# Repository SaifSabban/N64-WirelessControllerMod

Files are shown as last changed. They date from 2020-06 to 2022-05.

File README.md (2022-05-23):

# N64 -Wireless Controller Mod
A modification to your current N64 controller to make it wireless. Based on the Work by micro on the [Universal Wireless Retro Controller](https://nfggames.com/forum2/index.php?topic=5180.0) Click the photo to see a video of the controller in action.

<p align="center">
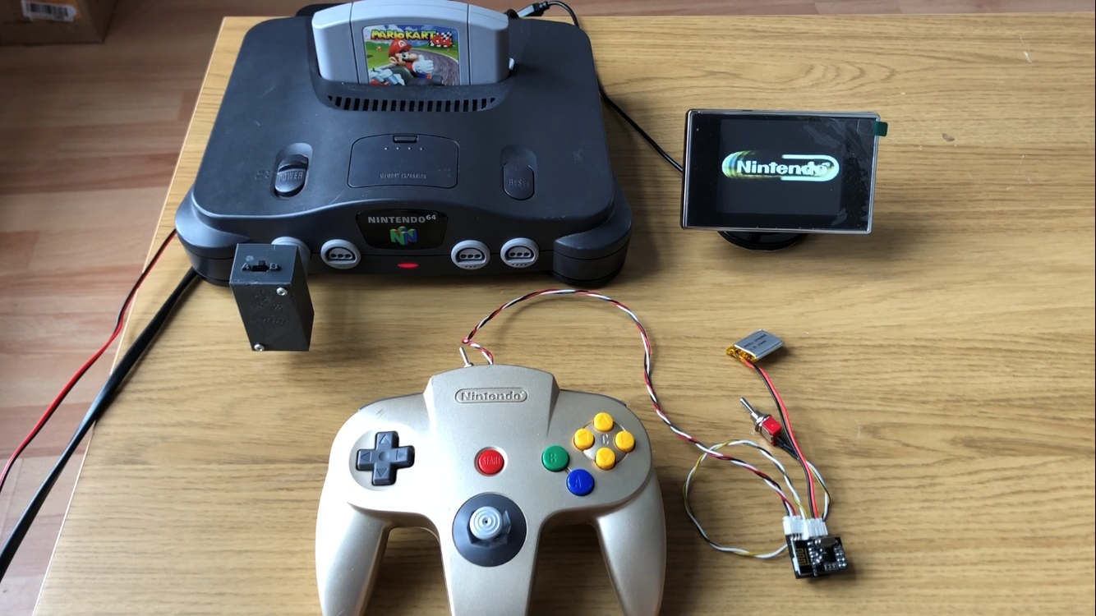
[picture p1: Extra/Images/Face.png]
IMAGE ALT TEXT HERE

<p>

### Notes
This project could use a lot of work, mainly:
1. We could integrate the NRF24L01+ into the PCB boards.
2. Add the components of the Micro-LiPo into the main transmitter PCB Board.
3. Translate the assembly code into Arduino code to allow the use of smaller micro controllers and possibly 2-way communication.

If you press the A button while powering the N64 controller with the mod, you will set the channel to A, while if you press B, you will set it to Channel B.

Know that if you decide to undertake this project, you are the one liable for any damages or risks that might occur.

## Getting Started
### Prerequisites
All the Components that are needed can be found in the bellow list:
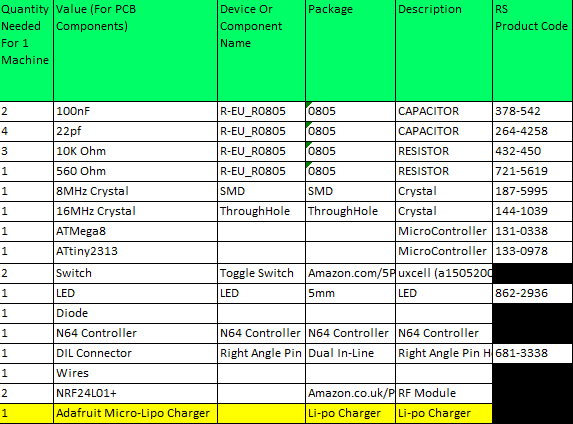
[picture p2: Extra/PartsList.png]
<p align="center"><p>

Optionally you could use JST connectors, instead of soldering wires directly to the PCB. I used the PH series.<br/>
you need to have an [ISP Arduino Programmer](https://docs.arduino.cc/built-in-examples/arduino-isp/ArduinoISP), or use any ISP programmer such as the [USBasp-Programmer](https://hobbycomponents.com/usb-interface/841-usbasp-avr-programmer-adaptor).<br/>
Install and set up [avrdudess](https://avrdudess.software.informer.com/2.4/) There are tons of write-ups on how to do this.<br/>
Print the Receiver's [3D box and Lid](https://github.com/saifsabban/N64-WirelessControllerMod/tree/master/3D-PrintableCase), and use two 2.5M screws to hold it down.<br/>
Print the PCBs for the [Reciever with a SMD microcontroller](https://github.com/saifsabban/N64-WirelessControllerMod/blob/master/N64_Receiver/N64_Receiver_PCB/N64_RX_GerberV2.1.zip) or [Receiver with a DIP microcontroller](https://github.com/saifsabban/N64-WirelessControllerMod/blob/master/N64_Receiver/N64_Receiver_PCB/N64_RX_GerberV2.0.zip) & the [Transmitter](https://github.com/saifsabban/N64-WirelessControllerMod/blob/master/N64_Transmitter/N64_Transmitter_PCB/N64_Tx_V4.0_Gerber.zip)

## Making the Receiver
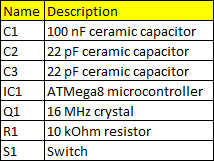
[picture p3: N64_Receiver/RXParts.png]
1. Populate the Receiver PCB with the appropriate parts (The essential resistors & capacitor can be either SMD or Through-Hole):<br/><p align="center"><p>
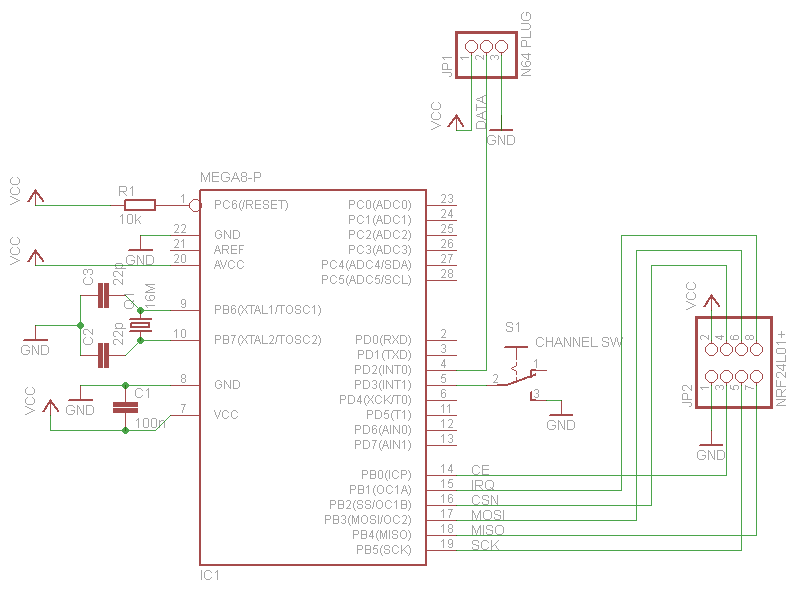
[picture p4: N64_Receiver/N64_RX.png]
2. Connect the ISP pins for your desired programmer to the Receiver Board. Hopefully this reference image and the PCB silkscreen will be of some help.<br/><p align="center"><p>
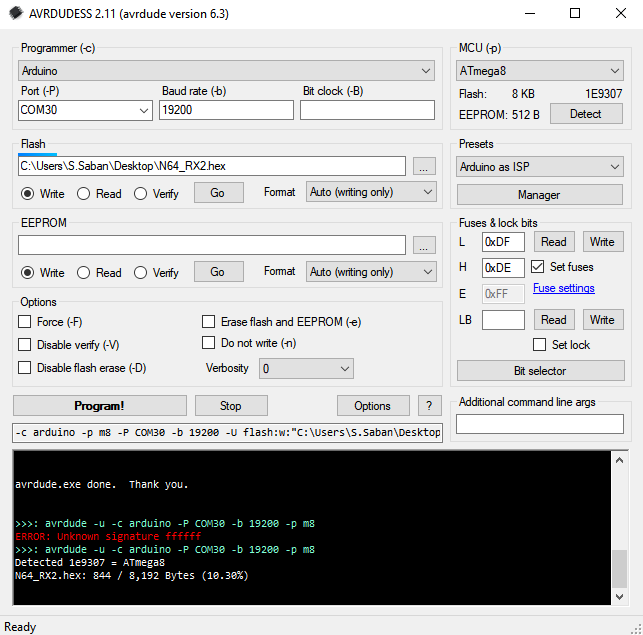
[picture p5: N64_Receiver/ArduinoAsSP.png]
3. Program the Board using AVRdudess with the same parameters shown, MAKE SURE THAT THE HIGH BYTE IS 0xDF & LOW BYTE IS 0xEE. If you don't then you might never be able to use that microcontroller again unless you change the crystal<br/><p align="center"><p>
4. Solder some wire to the switch and solder the other side to the PCB board's SW connector (It doesn't matter which pole of the switch connects to which pad).
5. Cut the N64 plug from the controller, making sure you have some length to route & solder to, I usually keep amount 20cm of cable and cut as necessary.
6. Check the fit of the plug to the printed box, some 3D printers make the opening too large or too small.
7. Glue the Connector to the BOX.
8. Solder the Red wire to the + pad on the connector labelled N64, the black wire to the pad labelled - and the white wire to the pad in the middle of both + & -.
9. Attach (or solder) the NRF24L01+ board onto the Receiver PCB.
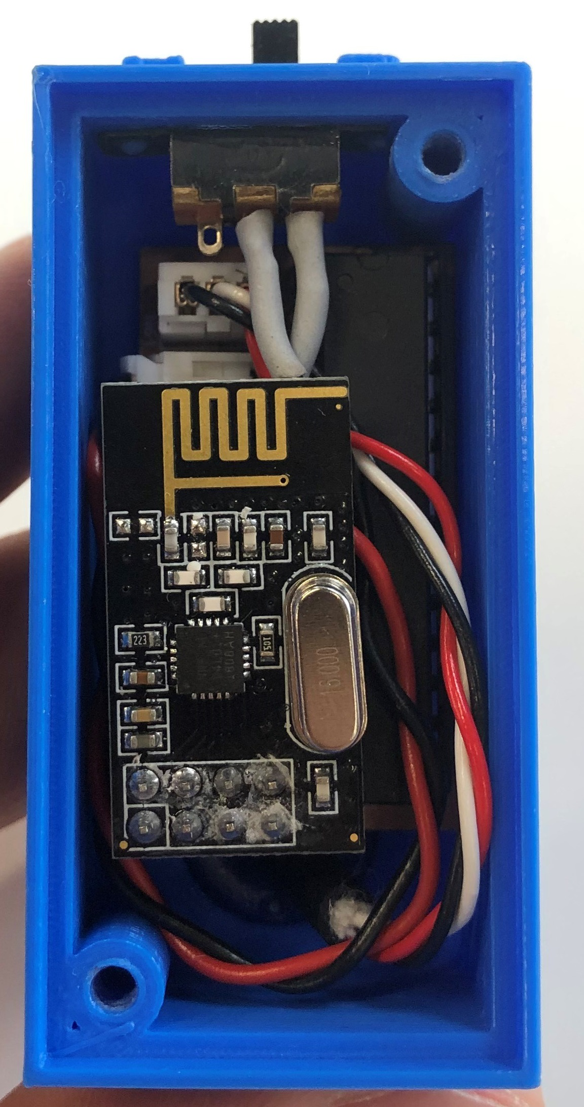
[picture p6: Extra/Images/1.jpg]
10. Place and glue all the parts inside the 3D printed box (As shown) and screw on the Lid<br/><p align="center"><p>

## Making the Transmitters
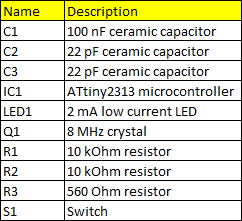
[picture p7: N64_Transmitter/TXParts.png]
1. Populate the Transmitter PCB with the appropriate parts:<br/><p align="center"><p>
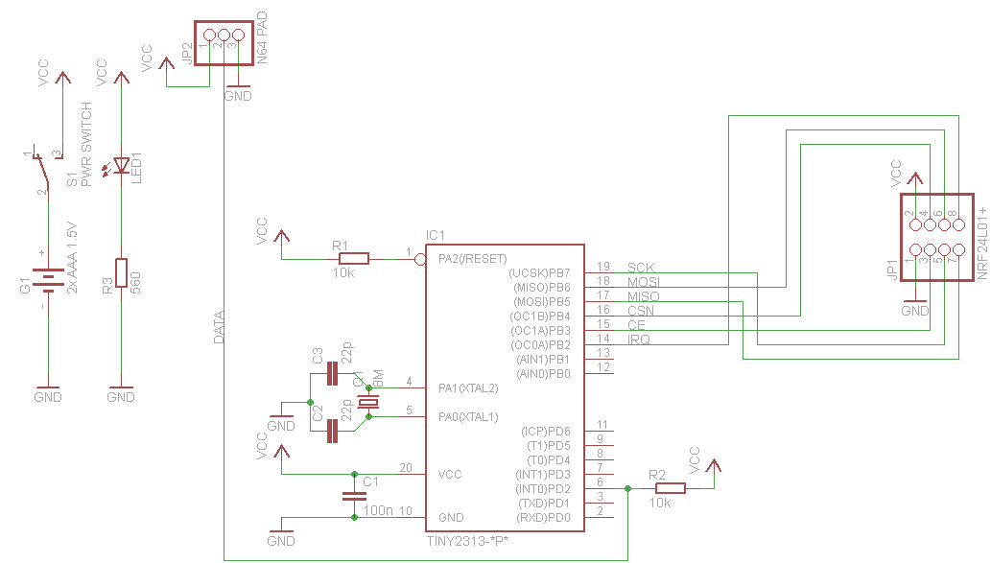
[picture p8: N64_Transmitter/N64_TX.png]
2. Connect the ISP pins for your desired programmer to the Transmitter Board. Hopefully this reference image will be of some help (the pins are in the same location as the connector on the Transmitter PCB, the Ground pin is the one that is highlighted)<br/><p align="center"><p>
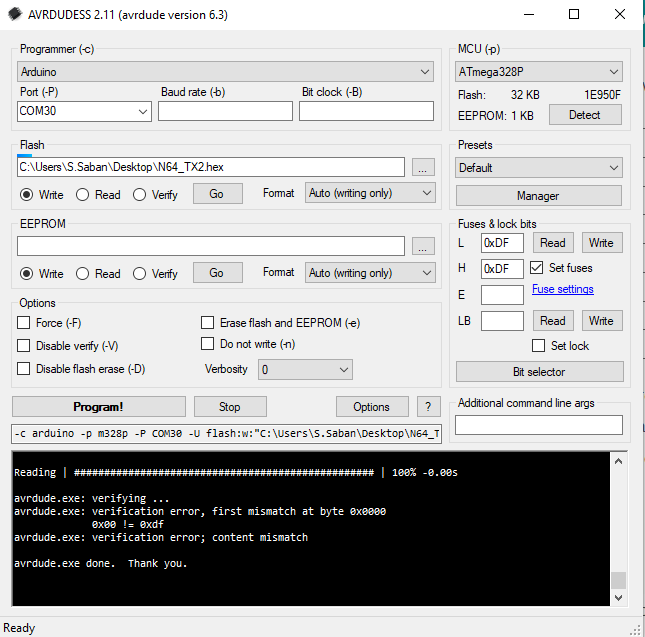
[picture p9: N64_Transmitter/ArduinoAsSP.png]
3. Program the Board using AVRdudess with the same parameters shown, MAKE SURE THAT THE HIGH BYTE IS 0xDF & LOW BYTE IS 0xDF. If you don't then you might never be able to use that microcontroller again unless you change the crystal<br/><p align="center"><p>
4. Disassemble the N64 Controller.
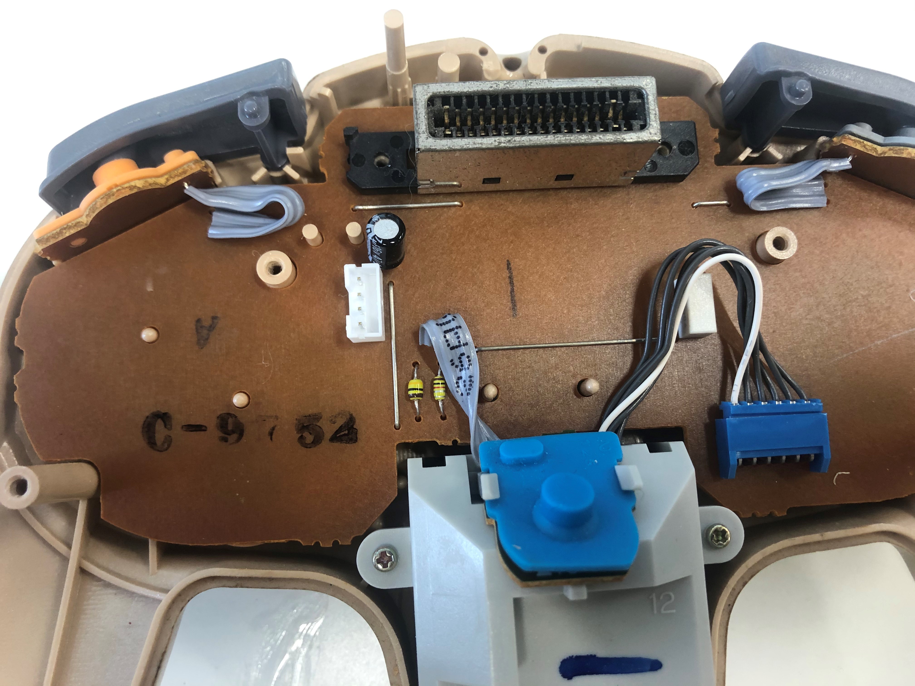
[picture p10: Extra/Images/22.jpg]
5. Desolder the original blue connector that connects to the cable. (I would strongly advise soldering a JST 4 pin PH female connector as shown in the photo below)<br/><p align="center"><p>
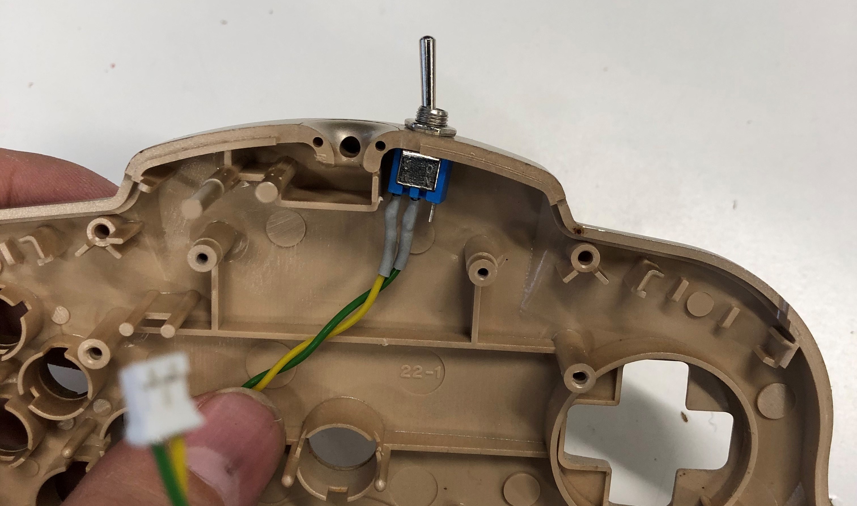
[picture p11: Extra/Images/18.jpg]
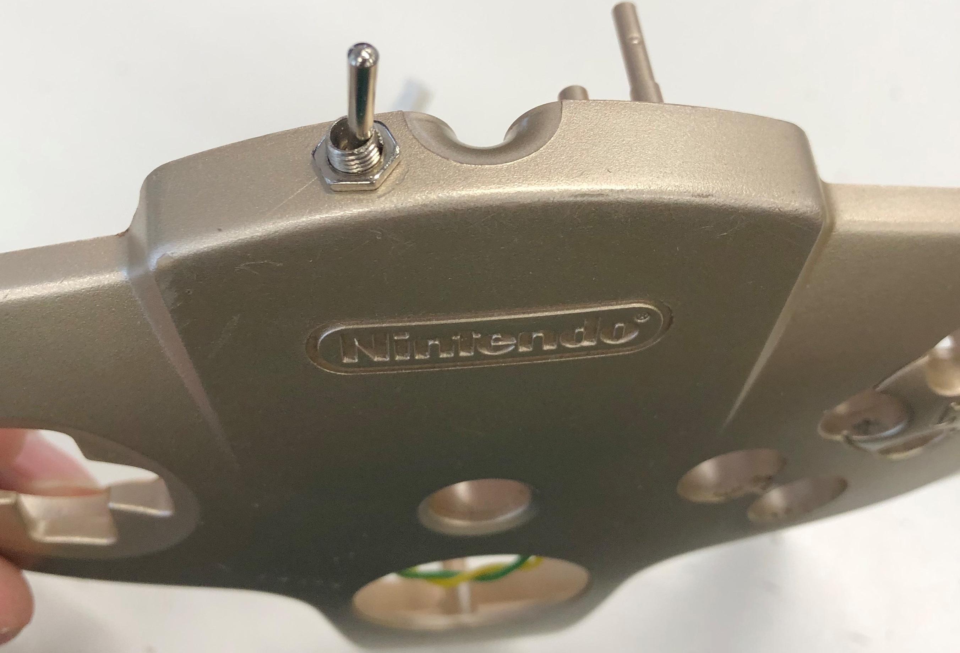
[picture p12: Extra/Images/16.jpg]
6. Check the Size of your switch as around 4.8mm, and proceed to drill a 5mm hole at the button half of the controller (See images), solder some wires to them and screw them onto the controller<br/><p align="center"><p><br/><p align="center"><p>
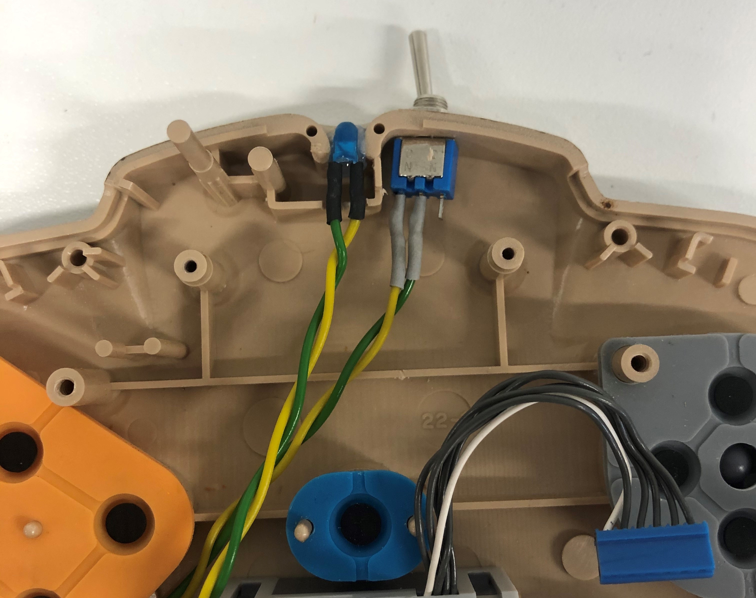
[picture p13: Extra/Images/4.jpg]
7. Solder some wires to the 5mm LED and hotglue it into the hole that the old controller wire used to come out of. (Keep a note which wire is positive and which is negative) <br/><p align="center"><p>
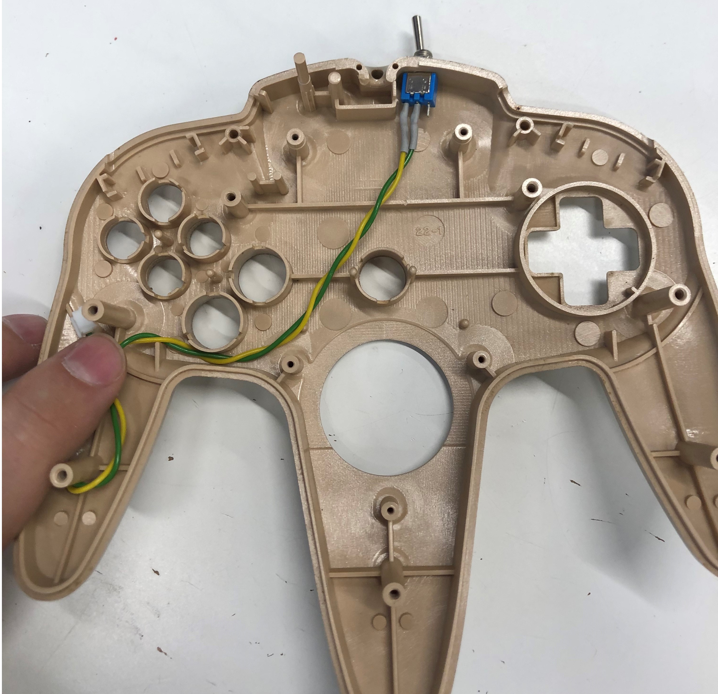
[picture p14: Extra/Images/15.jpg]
8. route the wires switch and LED wires to the "Right Hand" area of the controller.<br/><p align="center"><p>
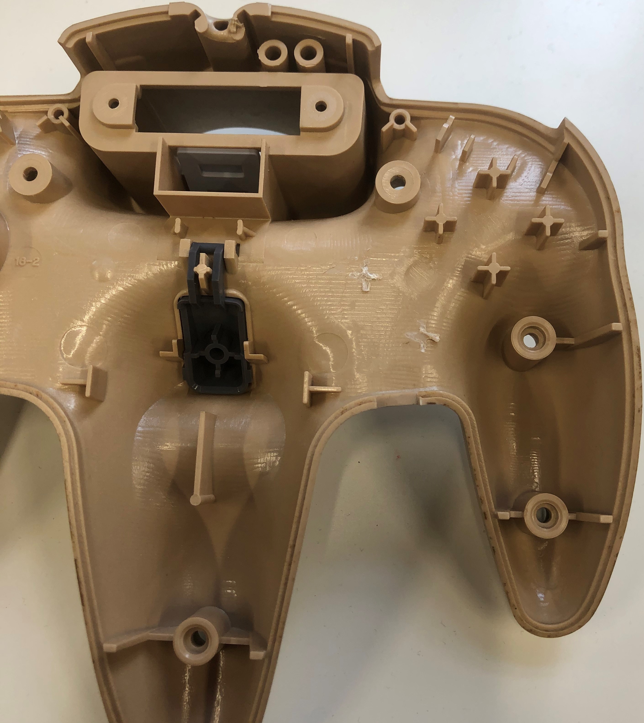
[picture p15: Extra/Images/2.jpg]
9. Remove the 2 lower "Crosses" that brace the buttons, from the bottom half of the controller.<br/><p align="center"><p>
10. solder wires to the "Bat" pin and the "GND" pin on the Adafruit Micro lipo.
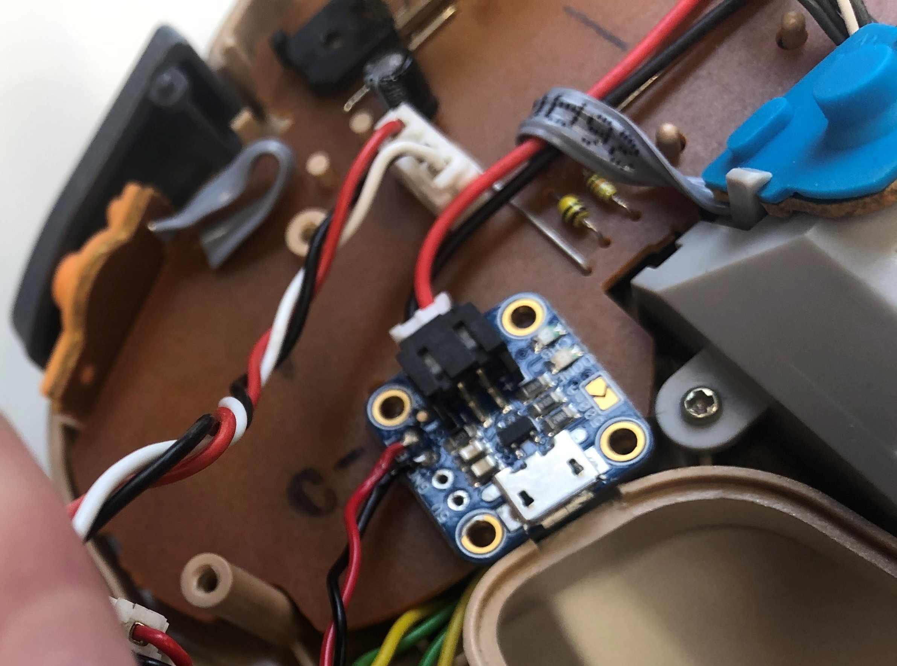
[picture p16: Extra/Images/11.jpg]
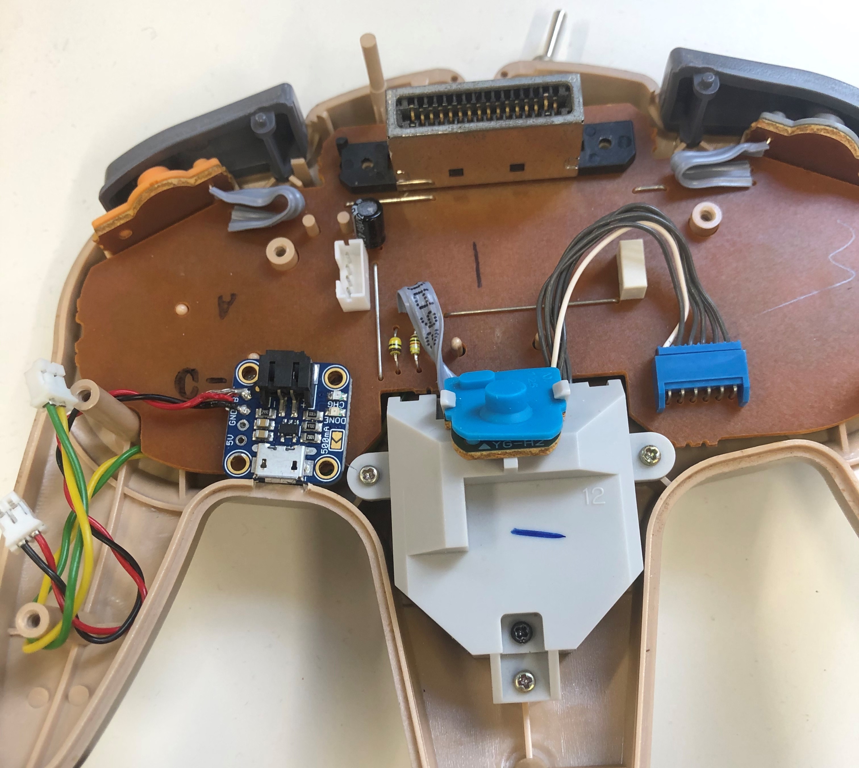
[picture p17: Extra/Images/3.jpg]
11. Place the Micro lipo at the Right-hand side of the controller, and cut a bit off the corresponding top and bottom half edges to allow the USB charger through.<br/><p align="center"><p><br/><p align="center"><p>
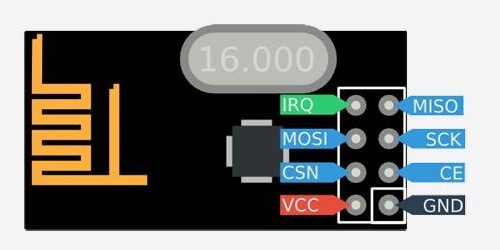
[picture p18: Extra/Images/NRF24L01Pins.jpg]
12. Desolder the Pins on the NRF24L01+ and solder wires to each pin, remembering which wire corresponds to which pin.<br/><p align="center"><p>
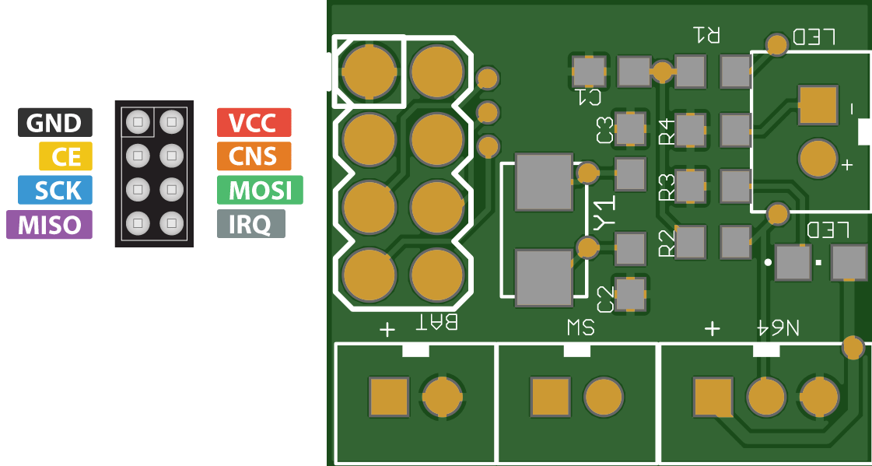
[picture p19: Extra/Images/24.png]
13. leave some length and solder the other side of the wires from step 11 to the Custom board.<br/><p align="center"><p>
14. Solder the LED and Switch wires to the Main PCB, making sure the polarity of the LED wires are correct (- pin is Ground, + pin is 3.3V).
15. Solder the wires from the Micro lipo, to the Custom board's Bat pins, making sure that the Bat pin solders to the pin marked with a +.
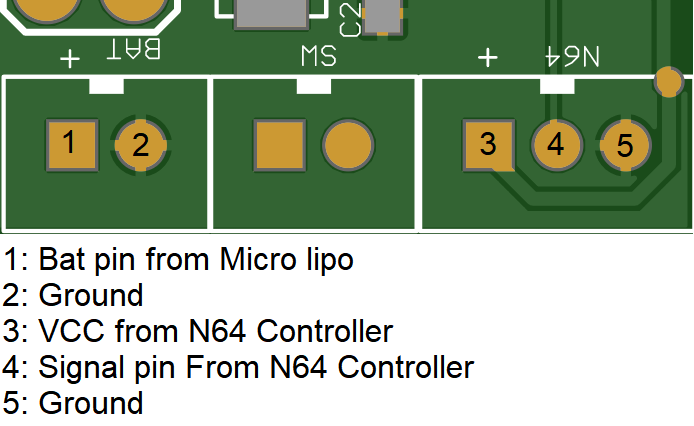
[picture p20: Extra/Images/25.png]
16. Solder the wires From the N64 controller board to the custom board, Pin order is VCC (Denoted by the + sign on top), signal wire, and ground. <br/><p align="center"><p>
17. Attach a battery to the micro lipo and test the mod. Remember if you press the A button while powering the N64 controller with the mod, you will set the channel to A, while if you press B, you will set it to Channel B.
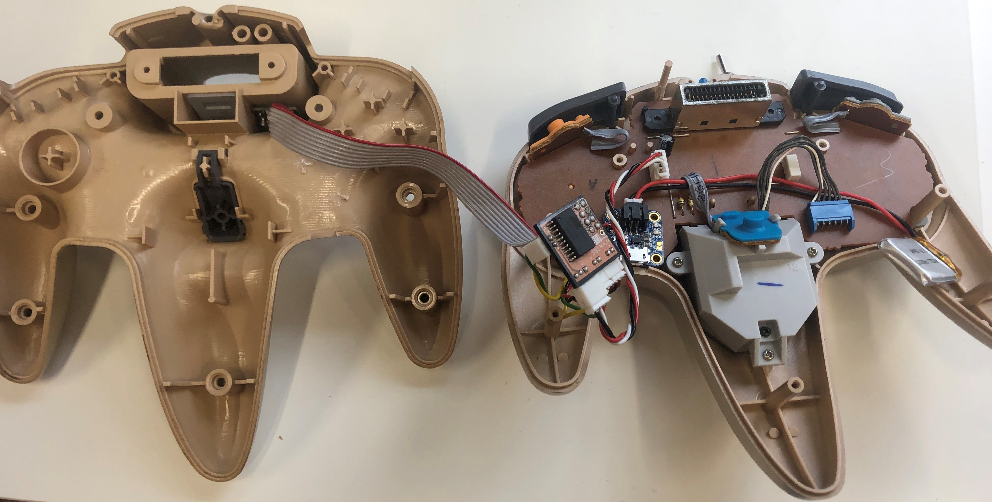
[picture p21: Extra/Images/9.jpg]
18. If all works button up your device. I recommend routing the battery to the Left hand side of the controller, the custom board to the Right, and feeding the NRF24L01+ into the nook of the expantion slot.<br/><p align="center"><p>

## Warnings!!
Make sure the polarity of the receiver pins is correct or you risk blowing the N64's power module, or worse, frying the N64 completely. In you connect the Batter pins or the N64 pins to the wrong wires you risk frying you N64 controller. I've tried this mod on reproduction N64 controllers, but it seems they allow some electrical noise that messes us the communication pathways and making it seem like you've pressed buttons you didn't actually press. If you mess with the power pins on the NRF24L01+ you risk breaking either your n64 or the controller, depending on which one was wrongfully connected. However, messing up the data pins of the NRF24L01+ breaks nothing. If the battery is too low, it will keep the LED light on, but might not send any control signals to the receiver.

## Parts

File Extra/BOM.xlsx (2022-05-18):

Quantity Needed For 1 Machine | Value (For PCB Components) | Device Or Component Name | Package | Description | RS Product Code | Cost For Each Component | Minimum Quantity Order | How Many Components Needed For All Machines | How Many Parts To Purchase For All Machines | Costs For Total Parts Needed To Make All Machines | Number of Machines
2 | 100nF | R-EU_R0805 | 0805 | CAPACITOR | 378-542 | £0.003 | 50 | 2 | 50 | £0.15 | 1
4 | 22pf | R-EU_R0805 | 0805 | CAPACITOR | 264-4258 | £0.010 | 25 | 4 | 25 | £0.25 | Make Cheaper By Making
3 | 10K Ohm | R-EU_R0805 | 0805 | RESISTOR | 432-450 | £0.004 | 100 | 3 | 100 | £0.40
1 | 560 Ohm | R-EU_R0805 | 0805 | RESISTOR | 721-5619 | £0.028 | 5 | 1 | 5 | £0.14
1 | 8MHz Crystal | SMD | SMD | Crystal | 187-5995 | £0.130 | 25 | 1 | 25 | £3.25
1 | 16MHz Crystal | ThroughHole | ThroughHole | Crystal | 144-1039 | £0.213 | 25 | 1 | 25 | £5.33
1 | ATMega8 |  |  | MicroController | 131-0338 | £1.860 | 2 | 1 | 2 | £3.72
1 | ATtiny2313 |  |  | MicroController | 133-0978 | £0.844 | 5 | 1 | 5 | £4.22
2 | Switch | Toggle Switch | Amazon.com/5Pcs-Thread-Latching-Toggle-Switch/dp/B0147XIKDE | uxcell (a15052000ux0140) |  | £1.000 | 5 | 2 | 5 | £5.00
1 | LED | LED | 5mm | LED | 862-2936 | £0.000 | 1 | 1 | 1 | £0.00
1 | Diode |  |  |  |  | £0.000 | 1 | 1 | 1 | £0.00
1 | N64 Controller | N64 Controller | N64 Controller | N64 Controller |  | £25.000 | 1 | 1 | 1 | £25.00
1 | DIL Connector | Right Angle Pin Header | Dual In-Line | Right Angle Pin Header | 681-3338 | £0.000 | 1 | 1 | 1 | £0.00
1 | Wires |  |  |  |  | £0.000 | 1 | 1 | 1 | £0.00
2 | NRF24L01+ |  | Amazon.co.uk/PIXNOR-Professional-NRF24L01-Wireless-Transceiver/dp/B010N32SGM/ref=sr_1_4?keywords=NRF24L01%2B&qid=1582118209&s=electronics&sr=1-4 | RF Module |  | £1.418 | 5 | 2 | 5 | £7.09
1 | Adafruit Micro-Lipo Charger |  | Li-po Charger | Li-po Charger | adafruit.com/product/1904 | £6.950 | 1 | 1 | 1 | £6.95
 |  |  |  |  |  |  |  |  | Total Cost For All Machines | £61.50
 |  |  |  |  |  |  |  |  | Relative Cost Of Each Machine | £61.50

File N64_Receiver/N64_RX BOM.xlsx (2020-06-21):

Part | Value | Footprint | RS Code
C1 | 100 nF | 0805 | 378-542
C2 | 22pF | 0805 | 264-4258
C3 | 22pF | 0805 | 264-4258
IC1 | ATMega8 |  | 131-0338
Y1 | 16MHz Crystal | Special | 144-1039
R1 | 10k Ohm | 0805 | 432-450
R2 | 560 Ohm | 0402 | 667-8668 |  | or a 0805 | 432-450
LED2 | Normal LED | 0805
S1 | Switch |  | 734-7154
NRF24L01+ | RF | 2x4 SIL |  | ebay.co.uk/i/293157600466?chn=ps&var=592026070810&norover=1&mkevt=1&mkrid=710-134428-41853-0&mkcid=2&itemid=592026070810_293157600466&targetid=878020360040&device=c&mktype=pla&googleloc=1006867&campaignid=9461445814&mkgroupid=97644908122&rlsatarget=pla-878020360040&abcId=1139576&merchantid=113716259&gclid=EAIaIQobChMI8suA6qCN6AIVia3tCh1bXAe_EAQYBSABEgKI2vD_BwE
Box | 30*60*20 | Hammond (1551HRBK) | 1974453 | uk.rs-online.com/web/p/general-purpose-enclosures/1974453

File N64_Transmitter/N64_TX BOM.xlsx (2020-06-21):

Part | Value | Footprint | RS Code
C1 | 100 nF | 0402 | 425-1510 | or a 0805 | 378-542 (https://uk.rs-online.com/web/p/mlccs-multilayer-ceramic-capacitors/0378542/)
C2 | 22pF | 0805 | 264-4258
C3 | 22pF | 0805 | 264-4258
IC1 | ATtiny2313 |  | 133-0978
LED1 | 2mA
LED2 | Normal LED | 0805
Y1 | 8MHz Crystal | Special | 187-5995
R1 | 10k Ohm | 0805 | 432-450 | or a 0402 | 430-767
R2 | 10k Ohm | 0805 | 432-450 | or a 0402 | 430-767
R3 | 560 Ohm | 0402 | 667-8668 | or a 0805 | 432-450
S1 | Switch |  | 734-7154
NRF24L01+ | RF | 2x4 SIL | ebay.co.uk/i/293157600466?chn=ps&var=592026070810&norover=1&mkevt=1&mkrid=710-134428-41853-0&mkcid=2&itemid=592026070810_293157600466&targetid=878020360040&device=c&mktype=pla&googleloc=1006867&campaignid=9461445814&mkgroupid=97644908122&rlsatarget=pla-878020360040&abcId=1139576&merchantid=113716259&gclid=EAIaIQobChMI8suA6qCN6AIVia3tCh1bXAe_EAQYBSABEgKI2vD_BwE
Diode?

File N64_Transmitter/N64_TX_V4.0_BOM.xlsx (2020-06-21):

Part | Value | Footprint | RS Code
C1 | 100nF | 0603 | 698-3251
C2 | 22pF | 0603 | 393-6716
C3 | 22pF | 0603 | 393-6716
IC1 | ATtiny2313 | Special | 133-0978
LED2 | Normal LED | 0805 | 692-0935
Y1 | 8MHz Crystal | Special | 813-6093
R1 | 10k Ohm | 0603 | 740-8805
R2 | 10k Ohm | 0603 | 740-8805
R3 | 560 Ohm | 0603 | 631-6339
R4 | 560 Ohm | 0603 | 631-6339
LED1 | 2mA | Wire
S1 | Switch |  | amazon.co.uk/5Pcs-Thread-Latching-Toggle-Switch/dp/B0147XIKDE
NRF24L01+ | RF | 2x4 SIL | ebay.co.uk/i/293157600466?chn=ps&var=592026070810&norover=1&mkevt=1&mkrid=710-134428-41853-0&mkcid=2&itemid=592026070810_293157600466&targetid=878020360040&device=c&mktype=pla&googleloc=1006867&campaignid=9461445814&mkgroupid=97644908122&rlsatarget=pla-878020360040&abcId=1139576&merchantid=113716259&gclid=EAIaIQobChMI8suA6qCN6AIVia3tCh1bXAe_EAQYBSABEgKI2vD_BwE

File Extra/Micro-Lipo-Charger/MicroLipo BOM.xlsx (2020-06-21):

Part | Value | Footprint | RS Code | Cost | minimum order
C1 | 10uF | 0805 | 749-2125 | 0.01 | 25
C2 | 10uF | 0805 | 749-2125 | 0.01 | 25
IC1 | MCP73831 | SOT-23 | 738-6360 | 0.434 | 5
CHG | Normal LED | 0805 | 654-5818 | 0.062 | 50
Done | Normal LED | 0805 | 121-7785 | 0.062 | 50
R1 | 470 Ohm | 0805 | 721-5619 | 0.009 | 25
R2 | 470 Ohm | 0805 | 721-5619 | 0.009 | 25
R3 | 10k Ohm | 0805 | 432-450 | 0.004
R3 | 2K Ohm | 0805 | 812-3508 | 0.01 | 25
USB | Micro USB | 105017-0001 | 848-6764 | 0.628 | 5
 |  |  |  | 1.238

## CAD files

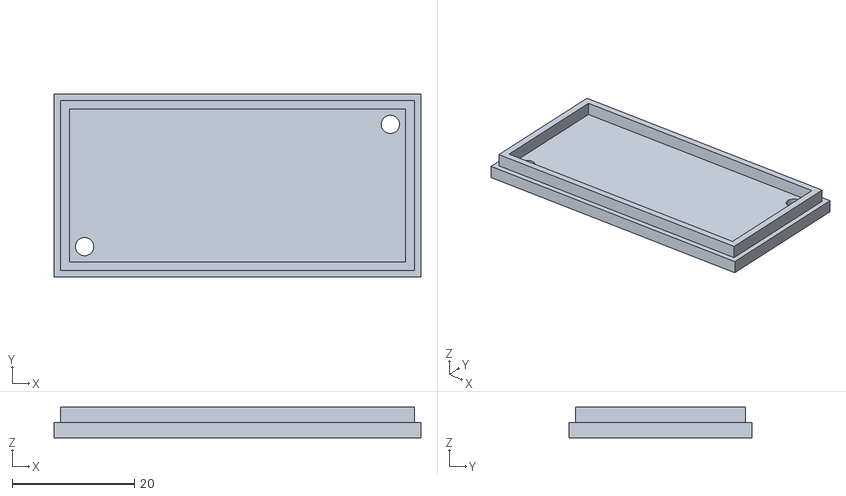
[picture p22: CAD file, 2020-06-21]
3D-PrintableCase/N64 Lid.stl
60.0 x 30.0 x 5.00

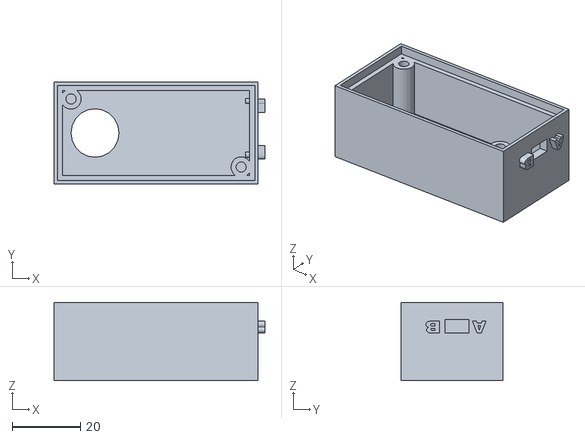
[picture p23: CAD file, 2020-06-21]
3D-PrintableCase/N64 Case.stl
62.0 x 30.0 x 23.0

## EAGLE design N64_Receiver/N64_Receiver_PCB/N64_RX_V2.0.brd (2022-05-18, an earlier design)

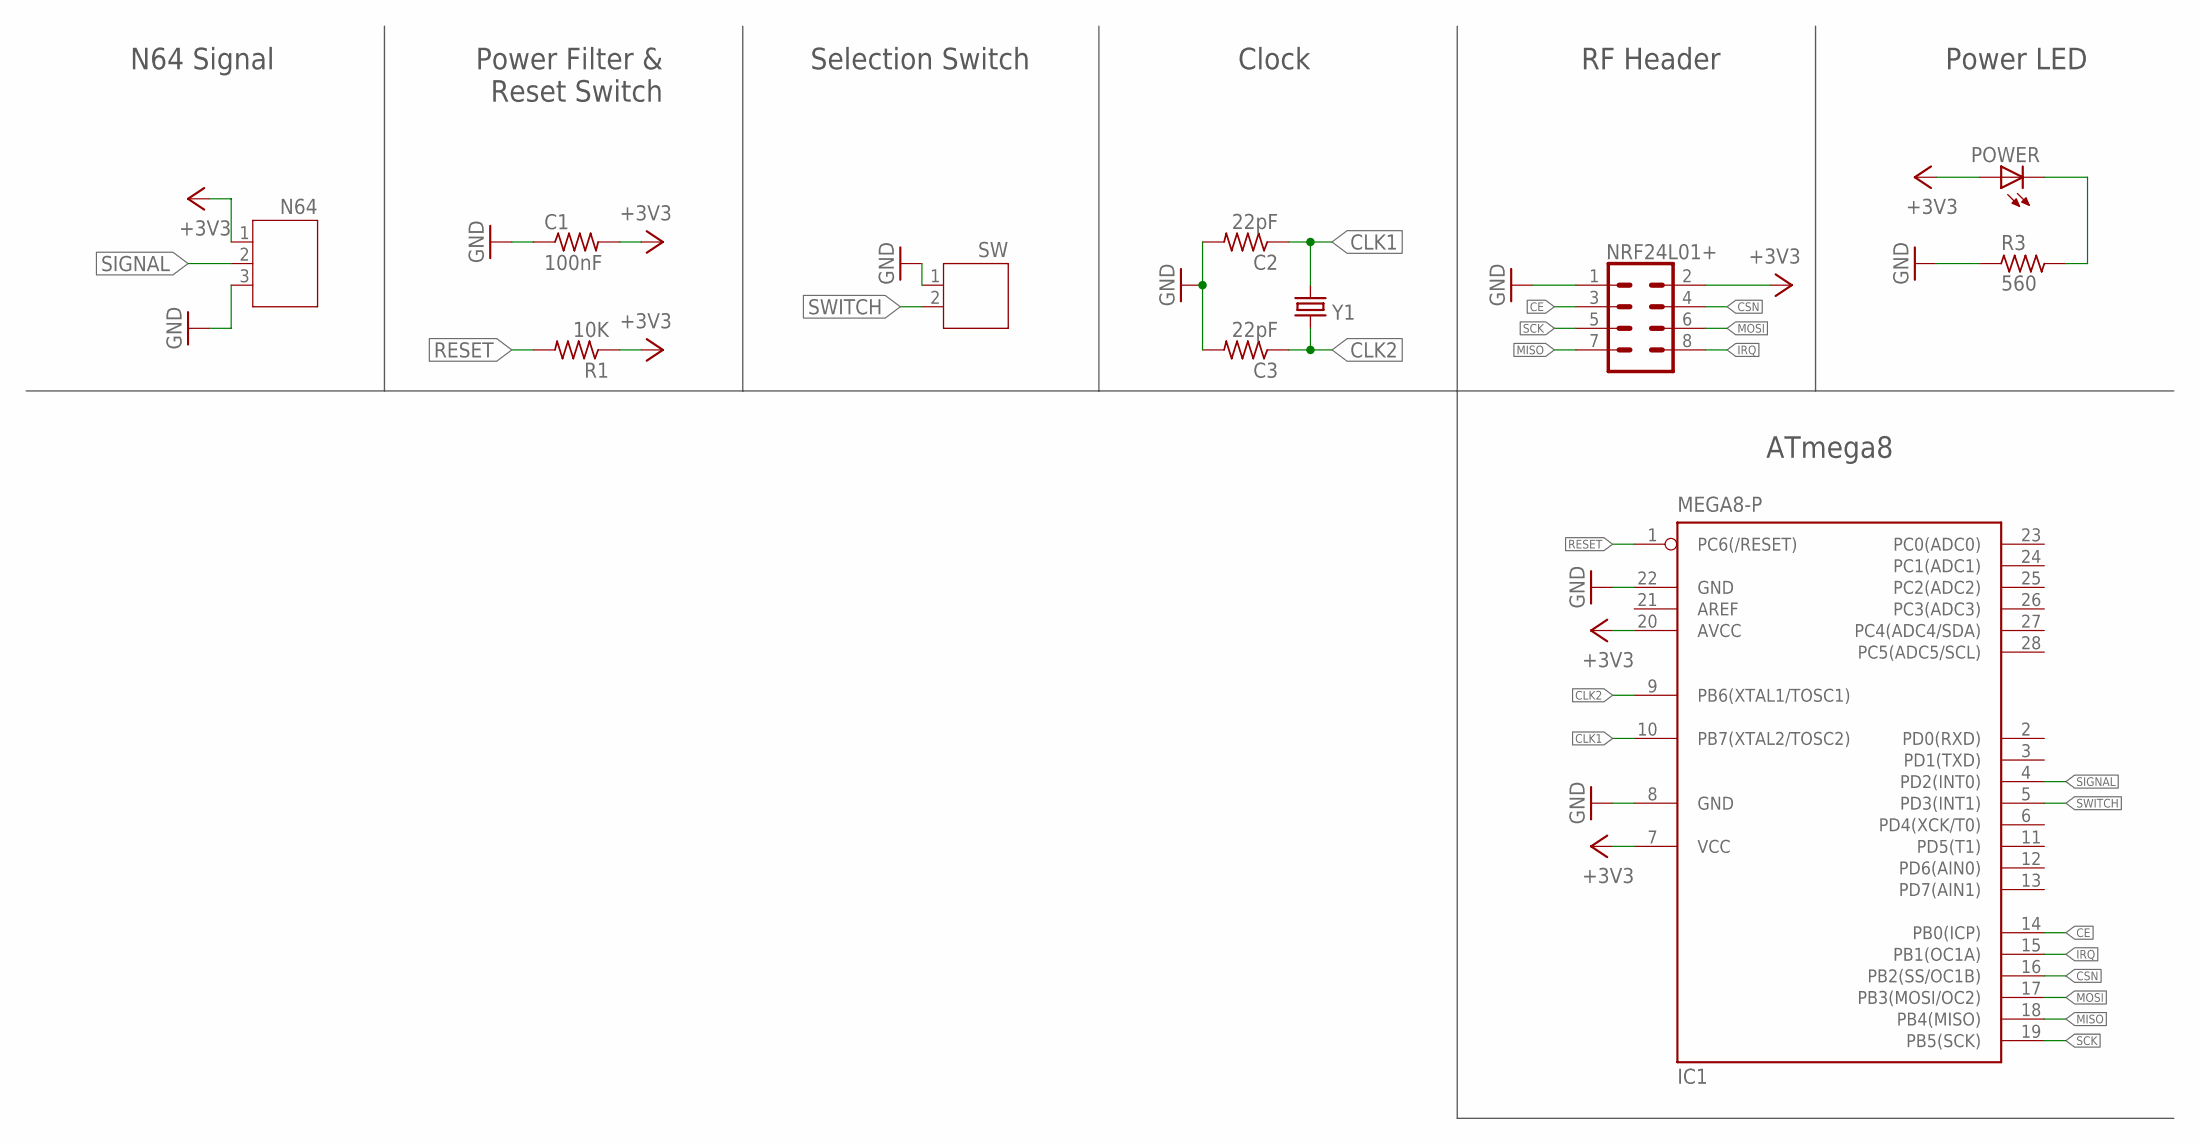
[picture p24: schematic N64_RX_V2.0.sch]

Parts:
C1: 100nF; 0805-THM
C2, C3: 22pF; 0805-THM
IC1: MEGA8-P; DIL28-3
N64: JST-PH3TH; JST-PH3
NRF24L01+: CONN_04X2; 2X4
POWER: LEDCHIPLED_0805; CHIPLED_0805
R1: 10K; 0805-THM
R3: 560; R0805
SW: JST-PH2TH; JST-PH2
Y1: CRYSTALHC49S; HC49/S

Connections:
+3V3: C1.2, IC1.7 (VCC), IC1.20 (AVCC), N64.1, NRF24L01+.2, POWER.A, R1.1
CE: IC1.14 (PB0(ICP)), NRF24L01+.3
CLK1: C2.1, IC1.10 (PB7(XTAL2/TOSC2)), Y1.2
CLK2: C3.1, IC1.9 (PB6(XTAL1/TOSC1)), Y1.1
CSN: IC1.16 (PB2(SS/OC1B)), NRF24L01+.4
GND: C1.1, C2.2, C3.2, IC1.8 (GND), IC1.22 (GND), N64.3, NRF24L01+.1, R3.1, SW.1
IRQ: IC1.15 (PB1(OC1A)), NRF24L01+.8
MISO: IC1.18 (PB4(MISO)), NRF24L01+.7
MOSI: IC1.17 (PB3(MOSI/OC2)), NRF24L01+.6
unnamed: POWER.C, R3.2
RESET: IC1.1 (PC6(/RESET)), R1.2
SCK: IC1.19 (PB5(SCK)), NRF24L01+.5
SIGNAL: IC1.4 (PD2(INT0)), N64.2
SWITCH: IC1.5 (PD3(INT1)), SW.2

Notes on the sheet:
N64 Signal
Power Filter & Reset Switch
Selection Switch
Clock
RF Header
ATmega8
Power LED

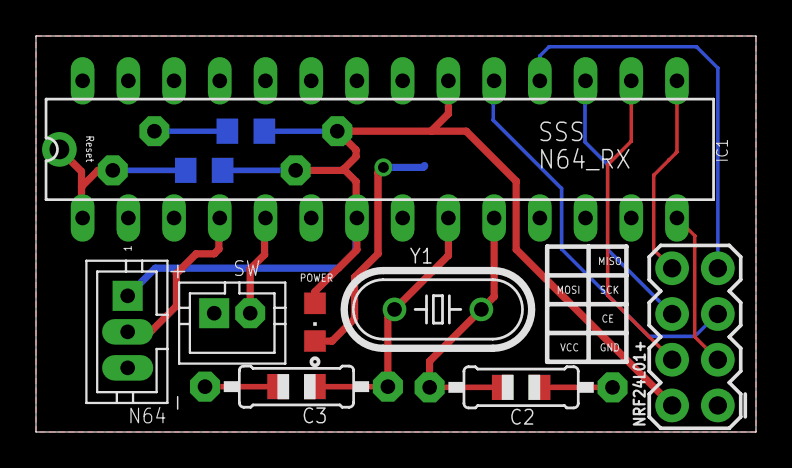
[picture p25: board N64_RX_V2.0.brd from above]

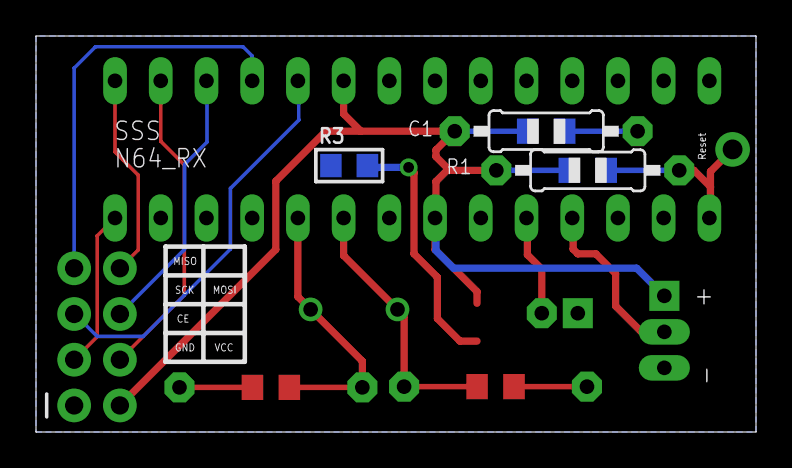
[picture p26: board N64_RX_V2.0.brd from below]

Board: 2 copper layers, 40.0 x 22.0 mm, 11 parts (3 on the bottom side), 14 nets.

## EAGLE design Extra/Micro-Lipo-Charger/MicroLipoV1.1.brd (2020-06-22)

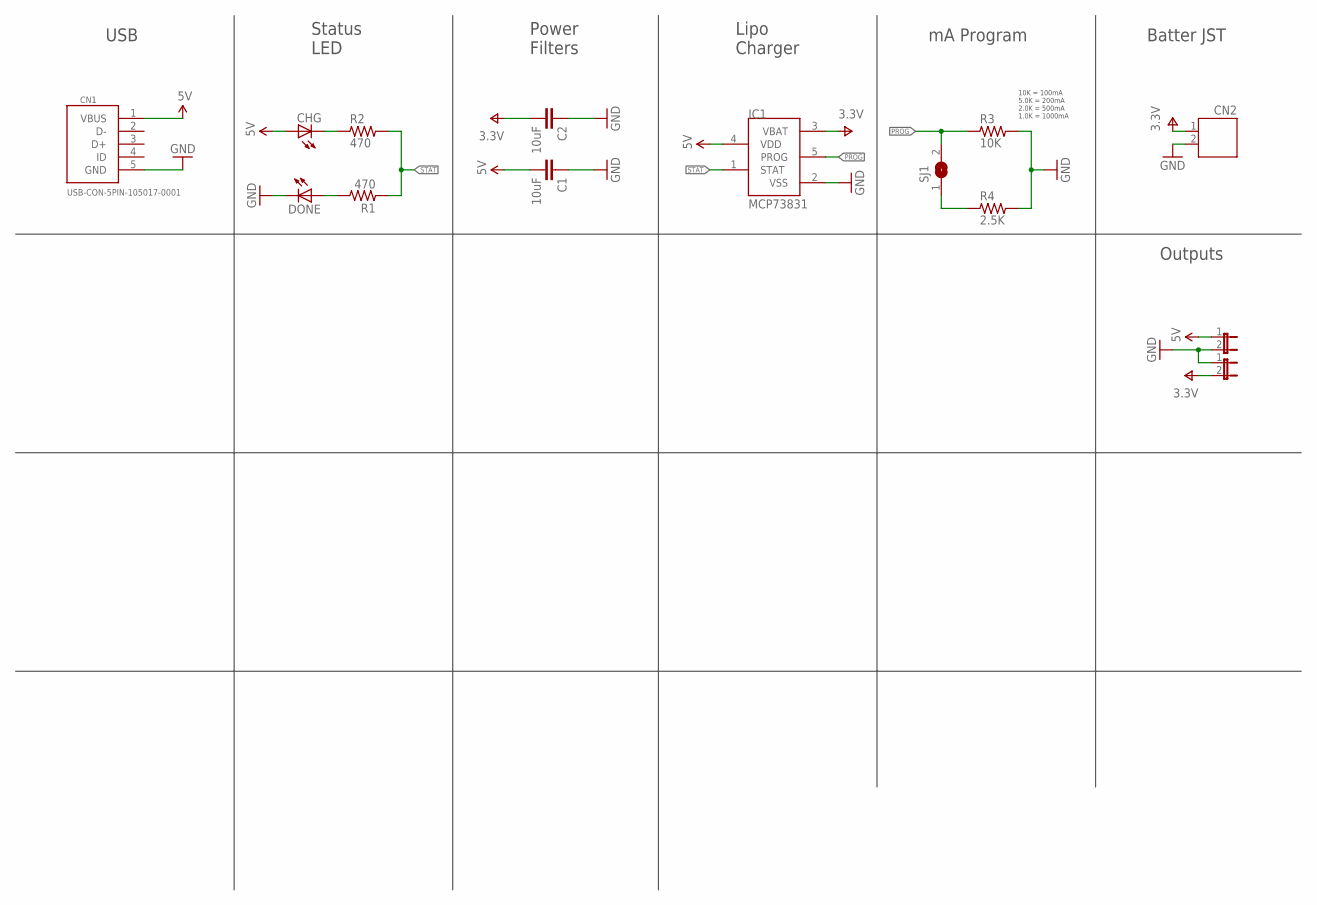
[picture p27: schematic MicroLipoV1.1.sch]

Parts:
C1, C2: 10uF; C0805K
CHG: LEDCHIPLED_0805; CHIPLED_0805
CN1: USB-CON-5PIN-105017-0001; USB-MICRO-MOLEX-105017-0001
CN2: JST-PH2; JST-PH2-S2B
DONE: LEDCHIPLED_0805; CHIPLED_0805
IC1: MCP73831; SOT23-5L
JP2, JP3: JUMPER-2PTH; 1X02
R1, R2: 470; R0805
R3: 10K; R0805
R4: 2.5K; R0805
SJ1: SJ

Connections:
5V: C1.2, CHG.A, CN1.1 (VBUS), IC1.4 (VDD), JP2.1
GND: C1.1, C2.1, CN1.5 (GND), CN2.2, DONE.C, IC1.2 (VSS), JP2.2, JP3.1, R3.2, R4.2
unnamed: CHG.C, R2.1
unnamed: DONE.A, R1.2
unnamed: R4.1, SJ1.1
PROG: IC1.5 (PROG), R3.1, SJ1.2
STAT: IC1.1 (STAT), R1.1, R2.2
V+: C2.2, CN2.1, IC1.3 (VBAT), JP3.2

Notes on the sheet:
USB
Status LED
Power Filters
Lipo Charger
mA Program
Batter JST
Outputs
10K = 100mA 5.0K = 200mA 2.0K = 500mA 1.0K = 1000mA

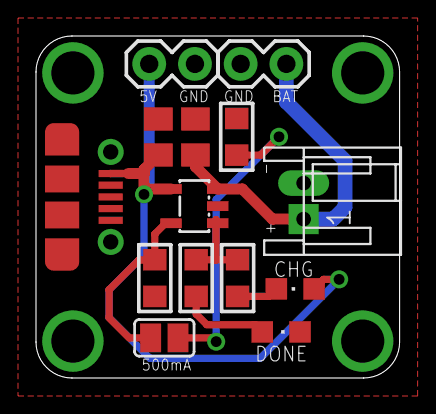
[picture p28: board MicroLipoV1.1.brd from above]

Board: 2 copper layers, 20.2 x 19.0 mm, 14 parts (0 on the bottom side), 8 nets.

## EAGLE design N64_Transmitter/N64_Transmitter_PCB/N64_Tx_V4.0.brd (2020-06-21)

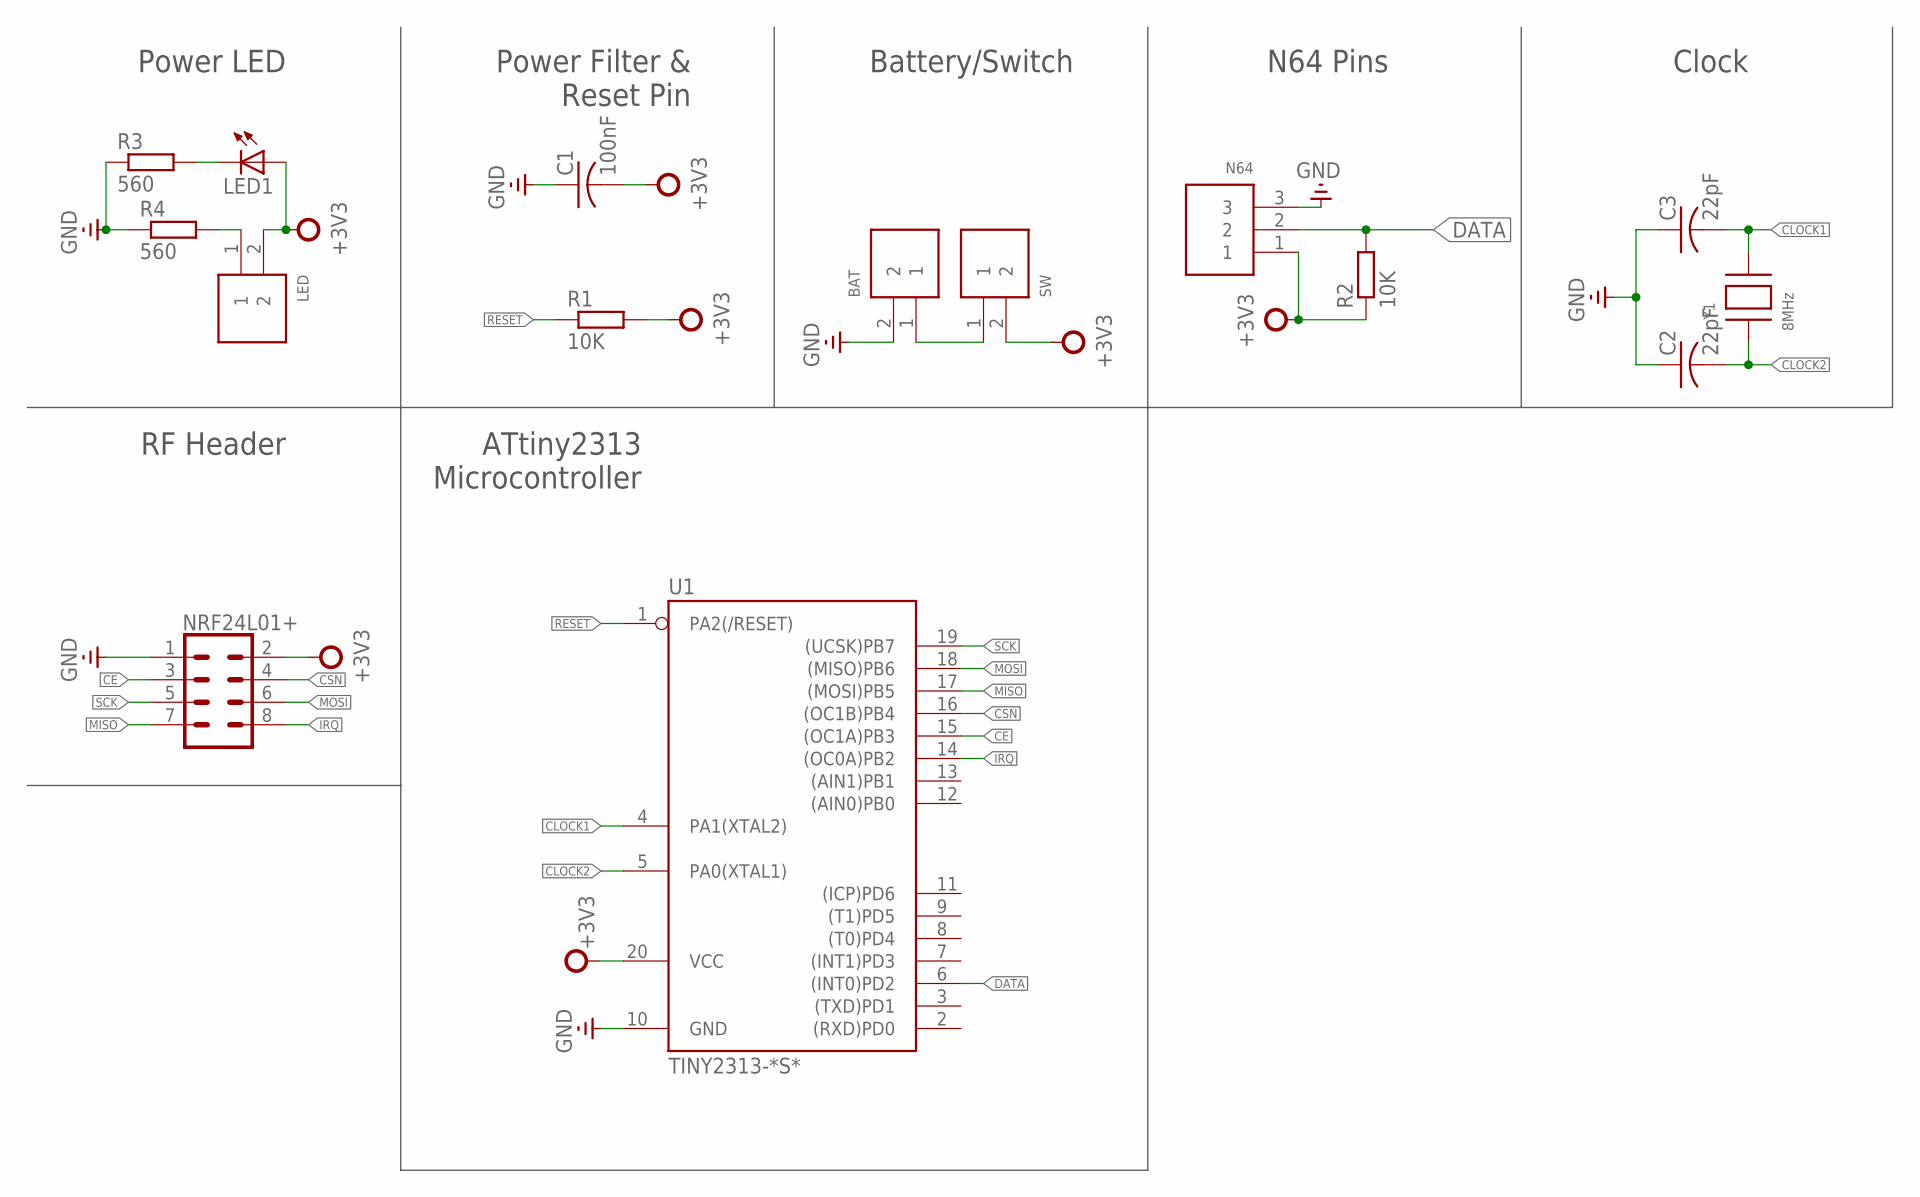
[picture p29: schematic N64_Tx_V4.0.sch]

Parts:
BAT: 2PIN; B2B-PH-K-S
C1: 100nF; C0603
C2, C3: 22pF; C0603
LED: 2PIN; B2B-PH-K-S
LED1: LEDCHIPLED_0805; CHIPLED_0805
N64: 3PIN; B3B-PH-K-S
NRF24L01+: CONN_04X2; 2X4
R1, R2: 10K; R0603
R3, R4: 560; R0603
SW: 2PIN; B2B-PH-K-S
U1: TINY2313-*S*; SO20L$
Y1: 8MHz; QANTEK_SMD_CRYSTAL_PACK

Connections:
+3V3: C1.2, LED.2, LED1.A, N64.1, NRF24L01+.2, R1.2, R2.1, SW.2, U1.20 (VCC)
CE: NRF24L01+.3, U1.15 ((OC1A)PB3)
CLOCK1: C3.2, U1.4 (PA1(XTAL2)), Y1.P$2 (X2)
CLOCK2: C2.2, U1.5 (PA0(XTAL1)), Y1.P$1 (X1)
CSN: NRF24L01+.4, U1.16 ((OC1B)PB4)
DATA: N64.2, R2.2, U1.6 ((INT0)PD2)
GND: BAT.2, C1.1, C2.1, C3.1, N64.3, NRF24L01+.1, R3.1, R4.1, U1.10 (GND)
IRQ: NRF24L01+.8, U1.14 ((OC0A)PB2)
MISO: NRF24L01+.7, U1.17 ((MOSI)PB5)
MOSI: NRF24L01+.6, U1.18 ((MISO)PB6)
unnamed: BAT.1, SW.1
unnamed: LED1.C, R3.2
unnamed: LED.1, R4.2
RESET: R1.1, U1.1 (PA2(/RESET))
SCK: NRF24L01+.5, U1.19 ((UCSK)PB7)

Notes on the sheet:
Power LED
Power Filter & Reset Pin
Battery/Switch
N64 Pins
Clock
RF Header
ATtiny2313 Microcontroller

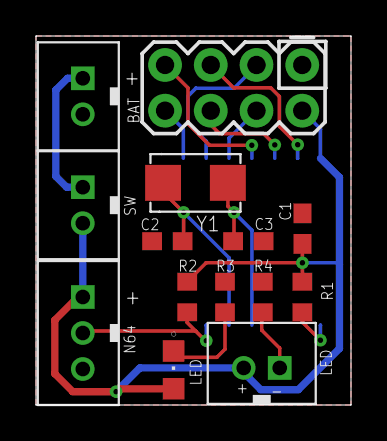
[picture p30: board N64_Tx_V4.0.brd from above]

Board: 2 copper layers, 17.5 x 20.5 mm, 15 parts (1 on the bottom side), 15 nets.

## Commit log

2020-06-21 Create Micro-Lipo-Charger
2022-05-18 Adding all the files
    [BOM.xlsx, Full List need To Get.xlsx, MicroLipo BOM.xlsx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]
2022-05-18 Added Dip Controller
    [N64_RX_V2.0.brd, N64_RX_V2.0.sch]

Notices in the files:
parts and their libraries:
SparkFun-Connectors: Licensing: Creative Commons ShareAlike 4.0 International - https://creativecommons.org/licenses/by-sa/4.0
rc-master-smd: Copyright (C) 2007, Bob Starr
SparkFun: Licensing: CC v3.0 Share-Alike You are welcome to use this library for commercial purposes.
